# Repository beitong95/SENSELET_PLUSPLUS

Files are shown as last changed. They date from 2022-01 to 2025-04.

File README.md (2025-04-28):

# SENSELET++
Github repo (code, hardware files) for 

**SENSELET++: A Low-cost Internet of Things Sensing Platform for Academic Cleanrooms**

Link: https://ieeexplore.ieee.org/abstract/document/9637790 

Please cite our work if you use SENSELET++:

```latex
@inproceedings{tian2021senselet++,
  title={Senselet++: A low-cost internet of things sensing platform for academic cleanrooms},
  author={Tian, Beitong and Yang, Zhe and Moeini, Hessam and Gupta, Ragini and Su, Patrick and Kaufman, Robert and McCollum, Mark and Dallesasse, John and Nahrstedt, Klara},
  booktitle={2021 IEEE 18th International Conference on Mobile Ad Hoc and Smart Systems (MASS)},
  pages={90--98},
  year={2021},
  organization={IEEE}
}
```

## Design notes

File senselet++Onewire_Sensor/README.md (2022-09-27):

# senseletonewire
# Raspberry Pi Zero W (Edge device preparation)
 -  download the latest raspbian
    ds28e17 driver is available after Linux-v4.15-rc1(raspbian buster or above)
 - country: united states; language: american English; timezone: chicago; use English language; use US keyboard; skip software update
 
 - set US keyboard for terminal, otherwise you cannot print "@"
    edit /etc/defaults/keyboard
    ```bash
    XKBLAYOUT="us"
    XKBMODEL="pc105" # XkbModel selects the keyboard model. This has an influence only for some extra keys your keyboard might have.
    ```

- set boot option
    boot to "console autologin text console"

- set interface option
    Please enable following interfaces with the following command or you can change boot/config.txt
    ```bash
     sudo raspi-config
    ```
    - ssh
    - i2c
    - serial
    - camera(if needed)

- set network
    Please connect to your own private network

- set up onewire driver and parameters
    disable w1-gpio in raspi-config [This is a default setting, so you don't need to do it.]

    Set up parameter: in "/etc/modprobe.d", create a file named "w1.conf"
    Then, add the following two lines in w1.conf
    ```bash
    options wire timeout=1 slave_ttl=1 #[search time, detect unplug time]
    options ds28e17 speed=100 #[set up ds28e17 i2c speed and stretch time]
    ```

    create "onewire.sh" in the home dir
    add the following two lines in onewire.sh
    ```bash
    modprobe ds2482 #[activate ds2482 driver]
    echo ds2482 0x18 > /sys/bus/i2c/devices/i2c-1/new_device #[detect ds2482]
    ```
    add "bash /home/pi/onewire.sh" in /etc/rc.local file to automatically run the script after booting
    
    **test if the above works:** 
    1. run lsmod to check active drivers
        sample result: 
        >wire 40960  4 ds2482,w1_ds2413,w1_ds2438,w1_ds28e17 (when you connnect the SenseEdge to the hat and sensors)
    
        or the result might be: 
        >wire 36864 1 ds2482 (when you only use the SenseEdge)
    
    2. check parameters
        go to ds28e17 device folder, run: 
        ```bash
        cat speed
        cat stretch
        ```
        then go to onewire master folder, run:
        ```bash
        cat timeout_second
        ```
    
- run edge data collect daemon
    get latest software on edge side

    ```bash
    cd $HOME
    git clone *this repo*
    ```

    before run senseletOneWire.py, you need to install some modules
    ```bash
    #install mosquitto client:
    sudo pip3 install paho-mqtt
    ```
    
    set mode to publish[remove all print]
    if you want to test, keep the mode as debug
    
    change raspberrypi_id to the right id [you can choose the id by your self]
    
    **[auto run]**
    add a daemon or add a command line in /etc/rc.local # actually, we dont need to add sudo because all commands run in the rc.local are run by sudoer. 
    ```bash
    sleep 30;bash /home/pi/onewire.sh;sudo python3 "your path to senseletOnewire.py" & #[add this line if you dont need log]
    sleep 30;bash /home/pi/onewire.sh;sudo python3 "your path to senseletOnewire.py" 2>&1 "your path to the log file" #[if you want a log]
    sleep 30;bash /home/pi/onewire.sh;sudo python3 -u "your path to senseletOnewire.py" 2>&1 | tee -i /some paths/"$(date '+%F-%T')_log.txt"& #[use this if you don't want to overwrite old log files everytime the raspberry pi reboots]
    ```
    
    **[manully run]**
    ```bash
    ssh to the edge device: ssh -p 22 pi@ip_address_of_the_device
    screen
    sudo python3 -u "your path to senseletOnewire.py" 2>&1 | tee -i log.txt
    ctrl+A; ctrl+D [exit screen]
    ctrl+D[exit ssh session]
    ```

# Server
> please see the Readme file in senselet++Onewire_Server

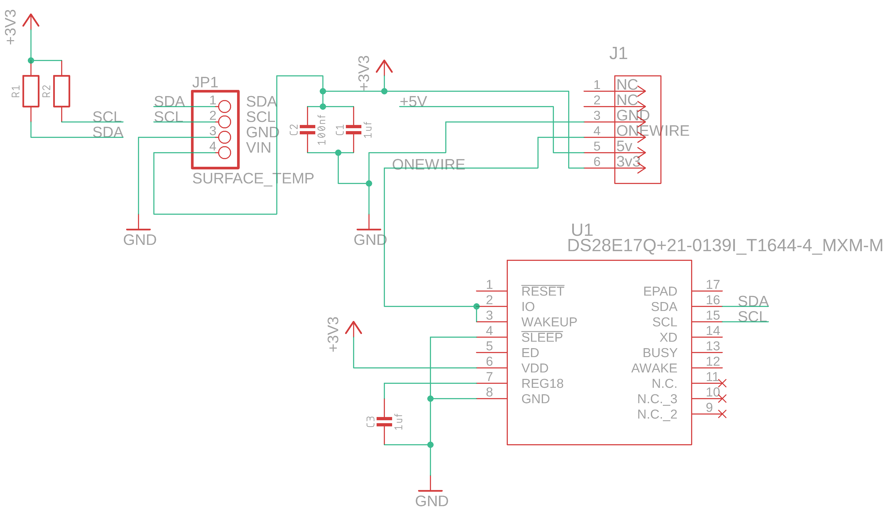
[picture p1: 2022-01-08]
Printed Circuit Board/Surface Temperature Sensor HiLetgo GY-906 MLX90614ESF/Surface Temperature Sensor DS28E17 Schematic.png

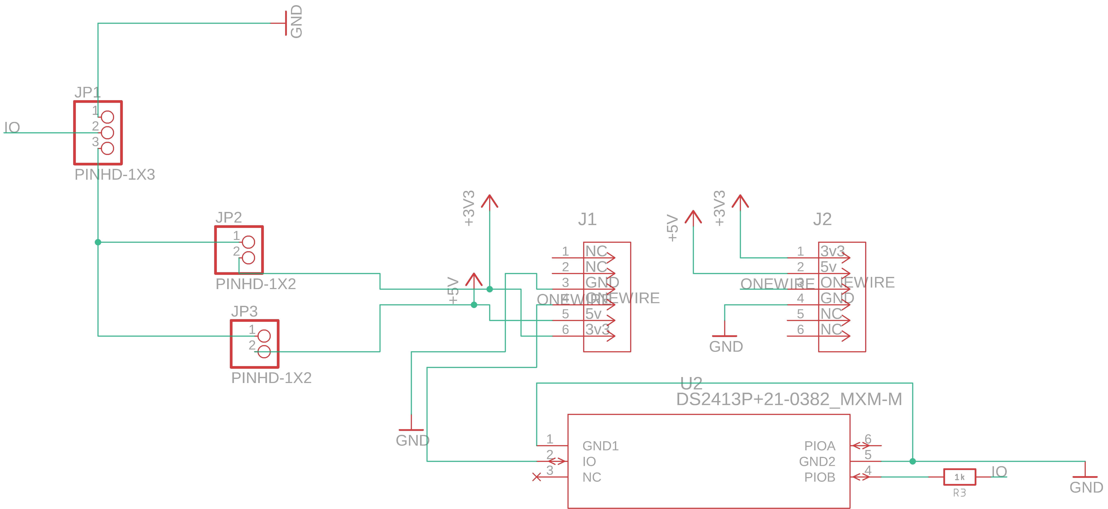
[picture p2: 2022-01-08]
Printed Circuit Board/Binary Output Sensor/Binary Output Sensor Schematic.png

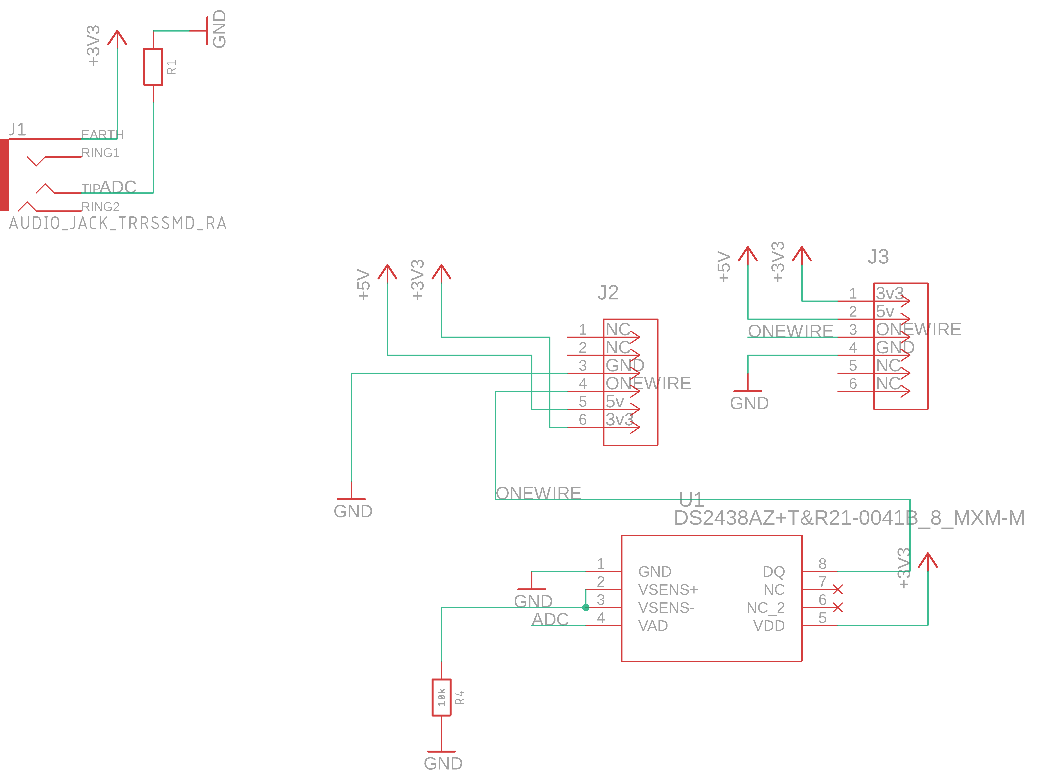
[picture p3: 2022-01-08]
Printed Circuit Board/Water Leakage Rope Sensor RCHWES4/Water Leakage Rope Sensor RCHWES4 Schematic.png

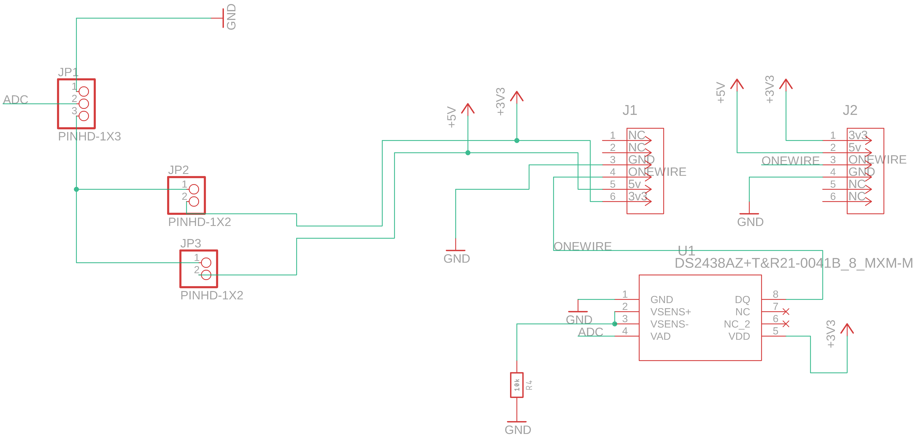
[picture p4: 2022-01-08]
Printed Circuit Board/Airflow Sensor D6F-V/Airflow Sensor D6F-V Schematic.png

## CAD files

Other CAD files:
3D Printed Closure/SenseEdge V4 with Raspberry Pi Zero W.f3z
3D Printed Closure/SenseEdge V4.f3z
3D Printed Closure/airflow sensor.f3d
3D Printed Closure/door sensor.f3d
3D Printed Closure/surface temperature sensor.f3d
3D Printed Closure/temperature & humidity.f3d
3D Printed Closure/water leakage point stand.f3d
3D Printed Closure/waterleakage point.f3d
3D Printed Closure/waterleakage rope.f3d

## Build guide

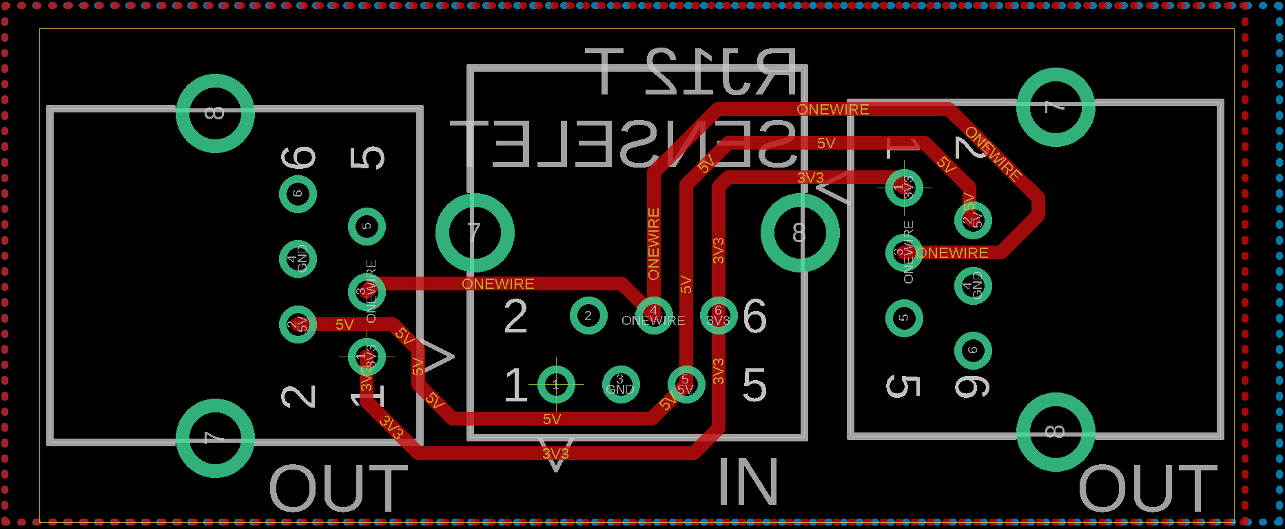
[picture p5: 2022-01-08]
Printed Circuit Board/T board/T board Board.png

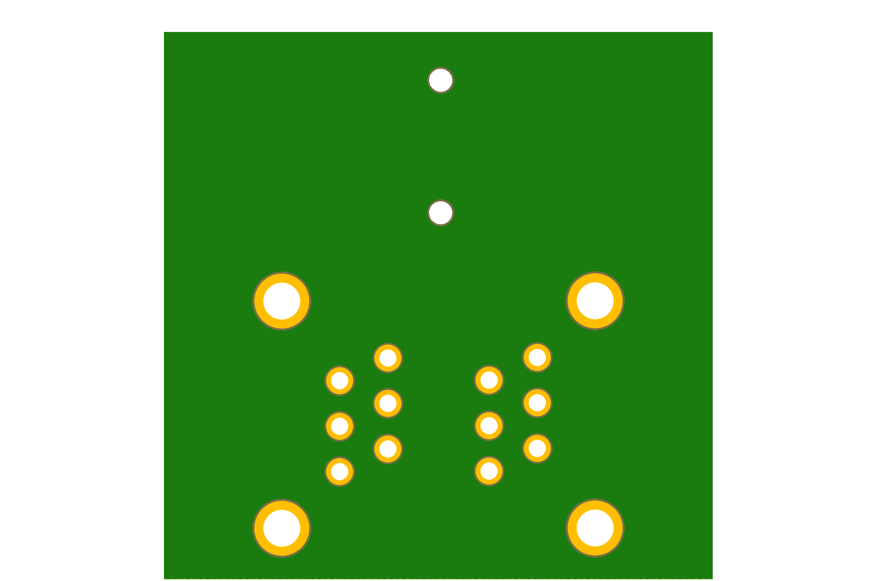
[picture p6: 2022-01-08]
Printed Circuit Board/Water Leakage Rope Sensor RCHWES4/Water Leakage Rope Sensor RCHWES4 Board Bottom.png

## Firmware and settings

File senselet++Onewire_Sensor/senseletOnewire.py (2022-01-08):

import paho.mqtt.client as paho
from sensorMetaData import sensorMetaData
from sht85 import SHT85
from mlx90614 import MLX90614
import os
import time 
import threading
from threading import Lock
from datetime import datetime
import subprocess

# lock for thread print
thread_print_lock = Lock()

# publish or debug
mode="publish"
#mode="debug"


# setup watchdog
fd = open("/dev/watchdog", "w")
print(fd)

# setup mqtt client and mqtt function
def on_publish(client,userdata,result):
    pass
broker="xxx.xxx.xxx.xxx"
port=1883
raspberrypi_id = 1
client = paho.Client("control" + str(raspberrypi_id))
client.on_publish = on_publish
client.connect(broker,port)
client.loop_start()

#global var
stationTXByte_old = 0
stationRXByte_old = 0
time_old = 0

# thread safe print 
def thread_print(a, *b):
    global mode
    # if we are sending the data to the server, we mute the output 
    if mode == "publish":
        return
    with thread_print_lock:
        # print format: time + data
        now = datetime.now()
        current_time = now.strftime("%H:%M:%S")
        print("%s: " % current_time, end='')
        print (a % b)

# sensor list
currentSensors = {}
ignore = 'w1_bus_master'

# Sensor Reading Class
# Each physical sensor will have a sensorReading obj
# There is no thread stop in python thread package, so we use stop flag to stop threads
class SensorReading(threading.Thread): 
  
    global client
    global fd
  
    def __init__(self, metaData): 
        threading.Thread.__init__(self) 
        self._stopper = threading.Event() 
        self.metaData = metaData
  
    def stop(self): 
        self._stopper.set() 
  
    def stopped(self): 
        return self._stopper.isSet() 

    def getInterval(self):
        return 1.0/self.metaData["frequency"]

    def getCalibration(self):
        return float(self.metaData["calibration"])

    def getID(self):
        return self.metaData["id"]

    def kickDog(self, ret):
        if ret.rc == 0:
            nb = fd.write("u")
            fd.flush()
            if nb > 0:
                pass
            else:
                thread_print("WATCHDOG ERROR")
        else:
            thread_print("Didn't kick the dog. ret value = %s" % str(ret.rc))

    def sht85_read(self):
        # get frequency
        interval = self.getInterval()
        calibration = self.getCalibration()
        # get id
        id = self.getID()

        while True: 
            if self.stopped(): 
                return
            t,h,c = self.metaData["i2cDevice"].single_shot("HIGH")
            h = h + calibration
            if c == 5:
                #read fail don't publish rare
                thread_print("sensor: %s. Read fail." % (id))
            else:
                # read success 
                # send r, h, id to the server
                thread_print("sensor: %s. Temp: %s. Hum: %s. Attempts: %s" % (id,str(t), str(h), str(c)))
                # publish 
                try:
                    ret = client.publish("senselet/" + id, str(time.time()) + '_' + str(t) + '_' + str(h))
                    self.kickDog(ret)
                except Exception as e:
                    thread_print(str(e))

            # adapt sleep time
            # after using ds2482, actually c will always be zero
            time.sleep(max(0.1, interval - (0.3*c + 0.2)))

    def mlx90614_read(self):
        # get frequency
        interval = self.getInterval()
        # get id
        id = self.getID()

        while True: 
            if self.stopped(): 
                return
            t,c = self.metaData["i2cDevice"].get_obj_temp()
            if c == 5:
                #read fail
                thread_print("sensor: %s. Read fail." % (id))
            else:
                # read success 
                # send r, h, id to the server
                thread_print("sensor: %s. Temp: %s.Attempts: %s" % (id,str(t), str(c)))
                try:
                    ret = client.publish("senselet/" + id, str(time.time()) + '_' + str(t))
                    self.kickDog(ret)
                except Exception as e:
                    thread_print(str(e))
            # adapt sleep time
            # after using ds2482, actually c will always be zero
            time.sleep(max(0.1, interval - 0.1*c))

    def waterLeakageRope_read(self):
        # get frequency
        interval = self.getInterval()
        # get id
        id = self.getID()
        while True: 
            if self.stopped(): 
                return

            # read adc
            path = "/sys/bus/w1/devices/" + id + "/vad"

            c = 0

            for i in range(5):
                try:
                    with  open(path, "r") as f:
                        status = f.read().replace("\n","")
                    break
                except IOError:
                    c = c + 1

            if c == 5 :
                #read fail
                thread_print("sensor: %s. Read fail." % (id))
            else:
                # read success 
                # convert adc reading to discrete status
                if int(status) < 300 and int(status) > 15:
                    status = 1
                else:
                    status = 0
                # send status to the server
                thread_print("sensor: %s. Status: %s. Attempts: %s" % (id,status, str(c)))
                try:
                    ret = client.publish("senselet/" + id, str(time.time()) + '_' + str(status))
                    self.kickDog(ret)
                except Exception as e:
                    thread_print(str(e))
            time.sleep(interval)

    def waterLeakagePoint_read(self):
        # get frequency
        interval = self.getInterval()
        # get id
        id = self.getID()

        while True: 
            if self.stopped(): 
                return
            path = "/sys/bus/w1/devices/" + id + "/state"

            c = 0
            for i in range(5):
                try:
                    with  open(path, "r") as f:
                        status = f.read(1)
                    break
                except IOError:
                    c = c + 1
            if c == 5 :
                #read fail
                thread_print("sensor: %s. Read fail." % (id))
            else:
                # read success 
                # send status to the server
                s = '{0:08b}'.format(ord(status))[1]
                thread_print("sensor: %s. Status: %s. Attempts: %s" % (id, s, str(c)))
                try:
                    ret = client.publish("senselet/" + id, str(time.time()) + '_' + s)
                    self.kickDog(ret)
                except Exception as e:
                    thread_print(str(e))

            time.sleep(interval)

    def doorSensor_read(self):
        # get frequency
        interval = self.getInterval()
        # get id
        id = self.getID()

        while True: 
            if self.stopped(): 
                return
            path = "/sys/bus/w1/devices/" + id + "/state"

            c = 0
            for i in range(5):
                try:
                    with  open(path, "r") as f:
                        status = f.read(1)
                    break
                except IOError:
                    c = c + 1
            if c == 5 :
                #read fail
                thread_print("sensor: %s. Read fail." % (id))
            else:
                # read success 
                # send status to the server
                s = '{0:08b}'.format(ord(status))[1]
                # convert: 1 is open 0 is close
                if s == "1":
                    s = "0"
                else:
                    s = "1"
                thread_print("sensor: %s. Status: %s. Attempts: %s" % (id, s, str(c)))
                try:
                    ret = client.publish("senselet/" + id, str(time.time()) + '_' + s)
                    self.kickDog(ret)
                except Exception as e:
                    thread_print(str(e))

            time.sleep(interval)

    def oilLeakagePoint_read(self):
        # get frequency
        interval = self.getInterval()
        # get id
        id = self.getID()

        while True: 
            if self.stopped(): 
                return
            path = "/sys/bus/w1/devices/" + id + "/state"

            c = 0
            for i in range(5):
                try:
                    with  open(path, "r") as f:
                        status = f.read(1)
                    break
                except IOError:
                    c = c + 1
            if c == 5 :
                #read fail
                thread_print("sensor: %s. Read fail." % (id))
            else:
                # read success 
                # send status to the server
                s = '{0:08b}'.format(ord(status))[1]
                thread_print("sensor: %s. Status: %s. Attempts: %s" % (id, s, str(c)))
                try:
                    ret = client.publish("senselet/" + id, str(time.time()) + '_' + s)
                    self.kickDog(ret)
                except Exception as e:
                    thread_print(str(e))

            time.sleep(interval)

    def airFlow_read(self):
        # get frequency
        interval = self.getInterval()
        # get id
        id = self.getID()
        while True: 
            if self.stopped(): 
                return

            # read adc
            path = "/sys/bus/w1/devices/" + id + "/vad"

            c = 0

            for i in range(5):
                try:
                    with  open(path, "r") as f:
                        status = f.read().replace("\n","")
                    break
                except IOError:
                    c = c + 1

            if c == 5 :
                #read fail
                thread_print("sensor: %s. Read fail." % (id))
            else:
                # read success 
                # send status to the server
                thread_print("sensor: %s. Speed: %s. Attempts: %s" % (id,status, str(c)))
                try:
                    ret = client.publish("senselet/" + id, str(time.time()) + '_' + str(status))
                    self.kickDog(ret)
                except Exception as e:
                    thread_print(str(e))
            time.sleep(interval)
  
    def run(self): 

        if self.metaData["name"] == "sht85":
            self.sht85_read()

        elif self.metaData["name"] == "mlx90614":
            self.mlx90614_read()

        elif self.metaData["name"] == "waterLeakageRope":
            self.waterLeakageRope_read()

        elif self.metaData["name"] == "waterLeakagePoint":
            self.waterLeakagePoint_read()

        elif self.metaData["name"] == "doorSensorSmall":
            self.doorSensor_read()

        elif self.metaData["name"] == "doorSensorLarge":
            self.doorSensor_read()

        elif self.metaData["name"] == "oilLeakagePoint":
            self.oilLeakagePoint_read()

        elif self.metaData["name"] == "airFlow":
            self.airFlow_read()
# Sensor Reading Class End

# get available devices in the folder
def getDevices():
    path = "/sys/bus/w1/devices/"
    try:
        files = os.listdir(path)
    except:
        return -1
    return files
    

# get the I2C BUS of a given sensor id
def getI2CBUS(sensor):
    path = "/sys/bus/w1/devices/" + sensor + "/"
    try:
        files = os.listdir(path)
    except:
        # oops fail to list dirs -> we unplug it
        return -1
    sub = "i2c"
    busName = [s for s in files if sub in s]
    if len(busName) == 0:
        #we have the file but no i2c -> we unplug it
        return -1
    return int(busName[0].split('-')[1])

def kickDog():
    thread_print("no sensor connect to the device %s." %(raspberrypi_id))


def checkAndUpdateSensors():
    start = time.time()
    global currentSensors

    if len(currentSensors) == 0:
        kickDog()

    # temp sensor list
    newSensors = {}
    # create a temp sensor list
    sensors = getDevices()
    if sensors == -1:
        return -1

    # if there is no sensor connecting to the edge, we still pat the dog

    # sensors are discovered by the driver
    for sensor in sensors:
        if ignore in sensor:
            continue
        if sensor not in sensorMetaData:
            # if the sensor is not registered, we print&log this error
            thread_print("sensor -  %s not registered" % sensor) 
            continue
        else:
            metaData = sensorMetaData[sensor]
            # if the sensor is registered, check if it is an i2c device(i2c device is a little bit complex)
            if metaData["protocol"] == "I2C":
                newI2cBus = getI2CBUS(sensor)
                if newI2cBus == -1 :
                    continue
                    
                else:
                    if metaData["name"] == "sht85":
                        newSensors[sensor] = {
                                "protocol": "I2C",
                                "i2cBus": newI2cBus,
                                "name": metaData["name"],
                                "frequency": metaData["frequency"],
                                "calibration": metaData["calibration"]
                                }
                    else:
                        newSensors[sensor] = {
                                "protocol": "I2C",
                                "i2cBus": newI2cBus,
                                "name": metaData["name"],
                                "frequency": metaData["frequency"]
                                }
            else:
                newSensors[sensor] = {
                        "protocol": metaData["protocol"],
                        "name": metaData["name"],
                        "frequency": metaData["frequency"]
                        }

    # loop through current sensor list, add new sensor, remove unplugged sensor
    # for i2c sensor, we need to check (1) if it exists in the currentSensors (2) if the i2c bus is the same
    for sensor in list(currentSensors):
        metaData = currentSensors[sensor]

        # unplug
        if sensor not in newSensors:
            # thread_print&log
            thread_print("sensor -  %s - %s unplugged" % (sensor, metaData["name"])) 
            # if this is I2C device, we need to close the I2C file
            if metaData["protocol"] == "I2C":
                metaData["i2cDevice"].bus.close()
            # stop the thread
            metaData["threading"].stop()
            metaData["threading"].join()
            # delete this sensor from the connected sensor list
            del currentSensors[sensor]

        else:
            # we need to do extra checks for I2C, we don't need to check sensors with other types
            if metaData["protocol"] == "I2C":
                # if the bus number does not change, do nothing. else, we close the old device and add the new device
                oldI2cBus = metaData["i2cBus"]
                newI2cBus = newSensors[sensor]["i2cBus"]
                if oldI2cBus != newI2cBus:
                    thread_print("i2c sensor change i2c bus from %s -> %s" % (str(oldI2cBus), str(newI2cBus))) 
                    metaData["i2cDevice"].bus.close()
                    # start new bus
                    if metaData["name"] == "sht85":
                        metaData["i2cDevice"] = SHT85(newI2cBus)
                    elif metaData["name"] == "mlx90614":
                        metaData["i2cDevice"] = MLX90614(newI2cBus)

            # delete this sensor from new Sensors list
            del newSensors[sensor]

            # for threading we dont need to do anything

    # remained sensors in newSensors are new plugged sensors
    for sensor in newSensors:
        metaData = newSensors[sensor]
        thread_print("sensor -  %s - %s plugged in to the system" % (sensor, metaData["name"])) 
        if metaData["protocol"]== "I2C":
            newI2cBus = newSensors[sensor]["i2cBus"]

            if metaData["name"]== "sht85":
                i2cDevice = SHT85(newI2cBus)
            elif metaData["name"]== "mlx90614":
                i2cDevice = MLX90614(0x5a,newI2cBus)

            if metaData["name"] == "sht85":
                currentSensors[sensor] = {
                                "id": sensor,
                                "protocol": "I2C",
                                "i2cBus": newI2cBus,
                                "i2cDevice": i2cDevice,
                                "name": metaData["name"],
                                "frequency": metaData["frequency"],
                                "calibration": metaData["calibration"]
                        }
            else:
                currentSensors[sensor] = {
                                "id": sensor,
                                "protocol": "I2C",
                                "i2cBus": newI2cBus,
                                "i2cDevice": i2cDevice,
                                "name": metaData["name"],
                                "frequency": metaData["frequency"]
                        }

        else:
            currentSensors[sensor] = {
                            "id": sensor,
                            "protocol": metaData["protocol"],
                            "name": metaData["name"],
                            "frequency": metaData["frequency"]
                    }
        # start sensor reading thread
        t  = SensorReading(currentSensors[sensor])
        currentSensors[sensor]["threading"] = t
        t.start()

    end = time.time()

# publish network stats
def publishLink():
    global raspberrypi_id
    id = 'network' + str(raspberrypi_id)
    process = subprocess.run('cat /proc/net/wireless', shell=True, check=True, stdout=subprocess.PIPE, universal_newlines=True)
    output = process.stdout
    outputList = output.split("\n")
    level = outputList[2].split()[2].replace('.','')
    thread_print("controller: %s. Link: %s. " % (id, level))
    try:
        ret = client.publish("senselet/" + id, str(time.time()) + '_' + level)
    except Exception as e:
        # we just print out the error
        thread_print(str(e))


def publishWIFIStats():
    global raspberrypi_id, stationTXByte_old, stationRXByte_old, time_old
    id = 'control' + str(raspberrypi_id)  
    process = subprocess.run('iw dev wlan0 station dump', shell=True, check=True, stdout=subprocess.PIPE, universal_newlines=True)
    output = process.stdout
    outputList = output.split('\n\t')
    stationMAC = str(outputList[0].split()[1])
    stationSignal = str(outputList[7].split('[')[1].split(']')[0]) 
    stationTXRate = str(outputList[8].split('\t')[1].split()[0])
    stationRXRate = str(outputList[9].split('\t')[1].split()[0])

    if stationTXByte_old == 0:
        time_old = time.time()
        stationTXByte_old = int(outputList[4].split('\t')[1])
        stationRXByte_old = int(outputList[2].split('\t')[1])
        stationTXByteRate = 0
        stationRXByteRate = 0
    else:
        time_new = time.time()
        time_diff = time_new - time_old
        stationTXByte_new = int(outputList[4].split('\t')[1])
        stationRXByte_new = int(outputList[2].split('\t')[1])
        stationTXByteRate = str(round((stationTXByte_new - stationTXByte_old)/time_diff ,3))
        stationRXByteRate = str(round((stationRXByte_new - stationRXByte_old)/time_diff,3))

        stationTXByte_old = stationTXByte_new
        stationRXByte_old = stationRXByte_new
        time_old = time_new
        
        thread_print("controller: %s. APMAC: %s. APTXByteRate: %s. APRXByteRate: %s. APSignal: %s. APTXRate: %s. APRXRate: %s. " % (id,stationMAC, stationTXByteRate, stationRXByteRate, stationSignal, stationTXRate, stationRXRate))
        try:
            ret = client.publish("senselet/" + id, str(time.time()) + '_' + stationMAC + '_' + stationTXByteRate + '_' + stationRXByteRate + '_' + stationSignal + '_' + stationTXRate + '_' + stationRXRate)
        except Exception as e:
            # we just print out the error
            thread_print(str(e))


def main():
    while True:
        try:
            # 04/16/2021 add wifi stats
            publishWIFIStats()
            ret = checkAndUpdateSensors()
            if ret == -1:
                thread_print("something wrong happened, lets try it agagin")
                time.sleep(0.5)
                continue
            # read link every 1 s    
            publishLink()
            time.sleep(1)
            publishLink()
            time.sleep(1)
            publishLink()
            time.sleep(1)
        except KeyboardInterrupt:
        # Ctrl-C handling and send kill to threads
            thread_print ("Sending kill to threads...")
            for sensor in currentSensors:
                currentSensors[sensor]["threading"].stop()
            for sensor in currentSensors:
                currentSensors[sensor]["threading"].join()
            break


    thread_print ("Exited")

if __name__ == '__main__':
   main()
   fd.write("V")
   fd.close()
   print("watch dog stop")

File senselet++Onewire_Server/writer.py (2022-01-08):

import paho.mqtt.client as mqtt
from influxdb import InfluxDBClient
from datetime import datetime
from threading import Timer
from collections import defaultdict
import sys
import pytz
import os
from sensorMetaData import sensorMetaData

# keep track the status of the door
doorStatus = {}
waterLeakageStatus = {}
latency_list = []
batched_points = []

def on_publish(client, userdata, result):
	print("TIMEOUT PUBLISHED!")

def on_connect(client, userdata, flags, rc):
	print("Connected with result code "+str(rc))
	client.subscribe("senselet/#")

def on_message(client, userdata, msg):
	global batched_points
	topic = msg.topic

	message = (msg.payload).decode('ascii')

	# initialize the data point 
	points = []
	point  = {}

	# extract sensor id from the message
	id = topic.split('/')[1]

	# first check if the sensor id is registered
	# if the sensor is not registered, we will print error message and skip this message
	if id not in sensorMetaData and 'control' not in id and 'Wireless' not in id and 'network' not in id:
		print("Register data inconsistent. Please check the metadatafile on the server side")
		return
	
	# store sensor id in tags
	point['tags']   = {'sensor': id}

	# extract and store time info 
	tt =   float(message.split('_')[0])
	print(topic+" "+message) # print the received message to stdout

	# extract and store sensory information
	if 'Wireless' in id:
		# wireless sensor
		information = message.split('_')
		if len(information) == 3:
			if information[1] == '1' or information[1] == '0':
				wirelessDoorStatus = float(information[1])
				battery = float(information[2])
				point['measurement'] = 'wirelessSensor'
				point['fields'] = {'doorStatus': wirelessDoorStatus, 'battery':battery}
				point['time']   = datetime.fromtimestamp(tt, pytz.utc).strftime('%Y-%m-%dT%H:%M:%SZ')
			elif information[1].isdigit():
				magnetic = int(information[1])
				battery = float(information[2])
				point['measurement'] = 'wirelessSensor'
				point['fields'] = {'magnetic': magnetic, 'battery':battery}
				point['time'] = int(tt)
				batched_points.append(point)
				if len(batched_points) >= 50:
					influx.write_points(batched_points, time_precision='u')
					batched_points = []
				return 
			else:
				return
	elif 'network' in id:
		point['time']   = datetime.fromtimestamp(tt, pytz.utc).strftime('%Y-%m-%dT%H:%M:%SZ')
		information = message.split('_')
		if len(information) == 2:
			LINK = float(information[1])
			point['measurement'] = 'wifi_measurement_new'
			point['fields'] = {'LINK': LINK}
		
	elif 'control' in id:
		point['time']   = datetime.fromtimestamp(tt, pytz.utc).strftime('%Y-%m-%dT%H:%M:%SZ')
		information = message.split('_')
		if len(information) == 7:
			APMAC = information[1]
			APTXBW = float(information[2])
			APRXBW = float(information[3])
			APRSSI = int(information[4])
			APTX = float(information[5])
			if information[6] == 'no':
				APRX = float(0)
			else:		
				APRX = float(information[6])
			point['measurement'] = 'wifi_measurement'
			point['fields'] = {'APMAC': APMAC, 'APTXBW': APTXBW, 'APRXBW': APRXBW, 'APRSSI': APRSSI, 'APTX': APTX, 'APRX': APRX}
		else:
			APMAC = information[1]
			APRSSI = int(information[2])
			APTX = float(information[3])
			APRX = float(information[4])
			point['measurement'] = 'wifi_measurement'
			point['fields'] = {'APMAC': APMAC, 'APRSSI': APRSSI, 'APTX': APTX, 'APRX': APRX}
	else: 
		point['time']   = datetime.fromtimestamp(tt, pytz.utc).strftime('%Y-%m-%dT%H:%M:%SZ')
		if sensorMetaData[id]['name'] == "sht85":
			temp = float(message.split('_')[1])
			humi = float(message.split('_')[2])
			point['measurement'] = 'temp_humi_measurement'
			point['fields'] = {'temperature': temp, 'humidity': humi}

		elif sensorMetaData[id]['name'] == "mlx90614":
			surfaceTemp = float(message.split('_')[1])
			point['measurement'] = 'surface_temp_measurement'
			point['fields'] = {'temperature': surfaceTemp}

		# 03112021 optimize door and water leakage sensor
		elif sensorMetaData[id]['name'] == "waterLeakageRope":
			# 1 is leaking; 0 is not leaking 
			isWaterLeaking = float(message.split('_')[1])
			if id in waterLeakageStatus:
				if isWaterLeaking == 1 or isWaterLeaking != waterLeakageStatus[id]:
					waterLeakageStatus[id] = isWaterLeaking
				else:
					print("skip writing for ", id, ",waterleakage = ", isWaterLeaking)
					return
			else:
				waterLeakageStatus[id] = isWaterLeaking
			point['measurement'] = 'waterLeakage_measurement'
			point['fields'] = {'isWaterLeaking': isWaterLeaking}

		elif sensorMetaData[id]['name'] == "waterLeakagePoint":
			# 1 is leaking; 0 is not leaking 
			isWaterLeaking = float(message.split('_')[1])
			if id in waterLeakageStatus:
				if isWaterLeaking == 1 or isWaterLeaking != waterLeakageStatus[id]:
					waterLeakageStatus[id] = isWaterLeaking
				else:
					print("skip writing for ", id, ",waterleakage = ", isWaterLeaking)
					return
			else:
				waterLeakageStatus[id] = isWaterLeaking
			point['measurement'] = 'waterLeakage_measurement'
			point['fields'] = {'isWaterLeaking': isWaterLeaking}

		elif sensorMetaData[id]['name'] == "oilLeakagePoint":
			# 1 is leaking; 0 is not leaking 
			isOilLeaking = float(message.split('_')[1])
			point['measurement'] = 'oilLeakage_measurement'
			point['fields'] = {'isOilLeaking': isOilLeaking}

		# 03112021 optimize door and water leakage sensor
		elif sensorMetaData[id]['name'] == "doorSensorSmall":
			# 1 is open; 0 is not open 
			isDoorOpen = float(message.split('_')[1])
			if id in doorStatus:
				if isDoorOpen == 1 or isDoorOpen != doorStatus[id]:
					doorStatus[id] = isDoorOpen
				else:
					print("skip writing for ", id, ",doorStatus = ", isDoorOpen)
					return
			else:
				doorStatus[id] = isDoorOpen
			# here we can add vacuum pump door measurement 
			point['measurement'] = 'door_measurement'
			point['fields'] = {'isDoorOpen': isDoorOpen}

		elif sensorMetaData[id]['name'] == "doorSensorLarge":
			# 1 is open; 0 is not open 
			isDoorOpen = float(message.split('_')[1])
			if id in doorStatus:
				if isDoorOpen == 1 or isDoorOpen != doorStatus[id]:
					doorStatus[id] = isDoorOpen
				else:
					print("skip writing for ", id, ",doorStatus = ", isDoorOpen)
					return
			else:
				doorStatus[id] = isDoorOpen
			point['measurement'] = 'door_measurement'
			point['fields'] = {'isDoorOpen': isDoorOpen}

		elif sensorMetaData[id]['name'] == "airFlow":
			# 1 is open; 0 is not open 
			airSpeed = float(message.split('_')[1])
			point['measurement'] = 'airFlow_measurement'
			point['fields'] = {'speed': airSpeed}

		elif sensorMetaData[id]['name'] == "openweather_sensor":
			temp = float(message.split('_')[1])
			humi = float(message.split('_')[2])
			rain = float(message.split('_')[3])
			snow = float(message.split('_')[4])
			pressure = float(message.split('_')[5])
			point['measurement'] = 'temp_humi_measurement'
			point['fields'] = {'temperature': temp, 'humidity': humi, 'rain': rain, 'snow': snow, 'pressure': pressure}
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

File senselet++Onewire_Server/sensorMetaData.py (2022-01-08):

sensorMetaData = {
            "19-00000003f4ee": {
                    "protocol": "I2C",
                    "name": "sht85",
                    "frequency": 1,
                    "calibration": 1.921
                }, 
            "19-000000040311": {
                    "protocol": "I2C",
                    "name": "sht85",
                    "frequency": 1,
                    "calibration": 1.092
                }, 
            "19-0000000408f9": {
                    "protocol": "I2C",
                    "name": "sht85",
                    "frequency": 1,
                    "calibration": -2.419
                }, 
            "19-00000003f81f": {
                    "protocol": "I2C",
                    "name": "sht85",
                    "frequency": 1,
                    "calibration": -1.609
                }, 
            "19-00000003f4c7": {
                    "protocol": "I2C",
                    "name": "sht85",
                    "frequency": 1,
                    "calibration": 0.25
                }, 
            "19-000000040b9d": {
                    "protocol": "I2C",
                    "name": "sht85",
                    "frequency": 1,
                    "calibration": -3.586
                }, 
            "19-00000003cb07": {
                    "protocol": "I2C",
                    "name": "sht85",
                    "frequency": 1,
                    "calibration": -0.264
                }, 
            "19-00000003cc7b": {
                    "protocol": "I2C",
                    "name": "sht85",
                    "frequency": 1,
                    "calibration": 0.149
                }, 
            "19-00000003bee6": {
                    "protocol": "I2C",
                    "name": "sht85",
                    "frequency": 1,
                    "calibration": -0.084
                }, 
            "19-00000003cb74": {
                    "protocol": "I2C",
                    "name": "sht85",
                    "frequency": 1,
                    "calibration": 0.351
                }, 
            "19-00000003ccb0": {
                    "protocol": "I2C",
                    "name": "sht85",
                    "frequency": 1,
                    "calibration": -0.155
                }, 
            "19-00000003cae2": {
                    "protocol": "I2C",
                    "name": "sht85",
                    "frequency": 1,
                    "calibration": 0.09
                }, 
            "19-00000003be4d": {
                    "protocol": "I2C",
                    "name": "sht85",
                    "frequency": 1,
                    "calibration": -1.83
                }, 
            "19-00000003bbc6": {
                    "protocol": "I2C",
                    "name": "sht85",
                    "frequency": 1,
                    "calibration": -0.409
                }, 
            "19-00000003d57f": {
                    "protocol": "I2C",
                    "name": "sht85",
                    "frequency": 1,
                    "calibration": 0.409
                }, 
            "19-00000003ffcf": {
                    "protocol": "I2C",
                    "name": "mlx90614",
                    "frequency": 1
                }, 
            "19-000000040923": {
                    "protocol": "I2C",
                    "name": "mlx90614",
                    "frequency": 1
                }, 
            "19-00000003c0dc": {
                    "protocol": "I2C",
                    "name": "mlx90614",
                    "frequency": 1
                }, 
            "19-00000003bc32": {
                    "protocol": "I2C",
                    "name": "mlx90614",
                    "frequency": 1
                }, 
            "19-00000003cc54": {
                    "protocol": "I2C",
                    "name": "mlx90614",
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
